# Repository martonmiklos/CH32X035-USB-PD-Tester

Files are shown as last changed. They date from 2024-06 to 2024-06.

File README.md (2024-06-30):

### What?

[This is the clone of this project](https://github.com/wagiminator/CH32X035-USB-PD-Tester)

Differences:
- Kicad 7+ (instead EasyEda)
- More generic pushbuttons
- Added programmer header
- Added load switch (for testing purposes)
- Changed voltage regulator to 3V3 as the
- Adoptable for LCDs with different pinouts (some exists with swapped GND and VDD pins)

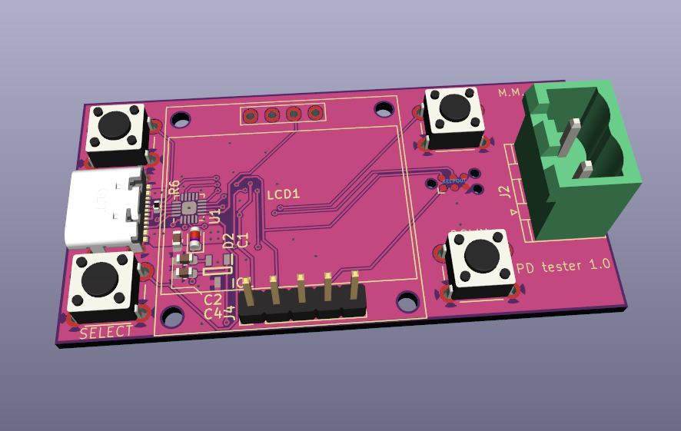
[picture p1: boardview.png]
board view Board


DO NOT BUILD IT YET. Mahor fuckups discovered during board bringup:
- The voltage regulator is not capable of supplying enought current to the LVD

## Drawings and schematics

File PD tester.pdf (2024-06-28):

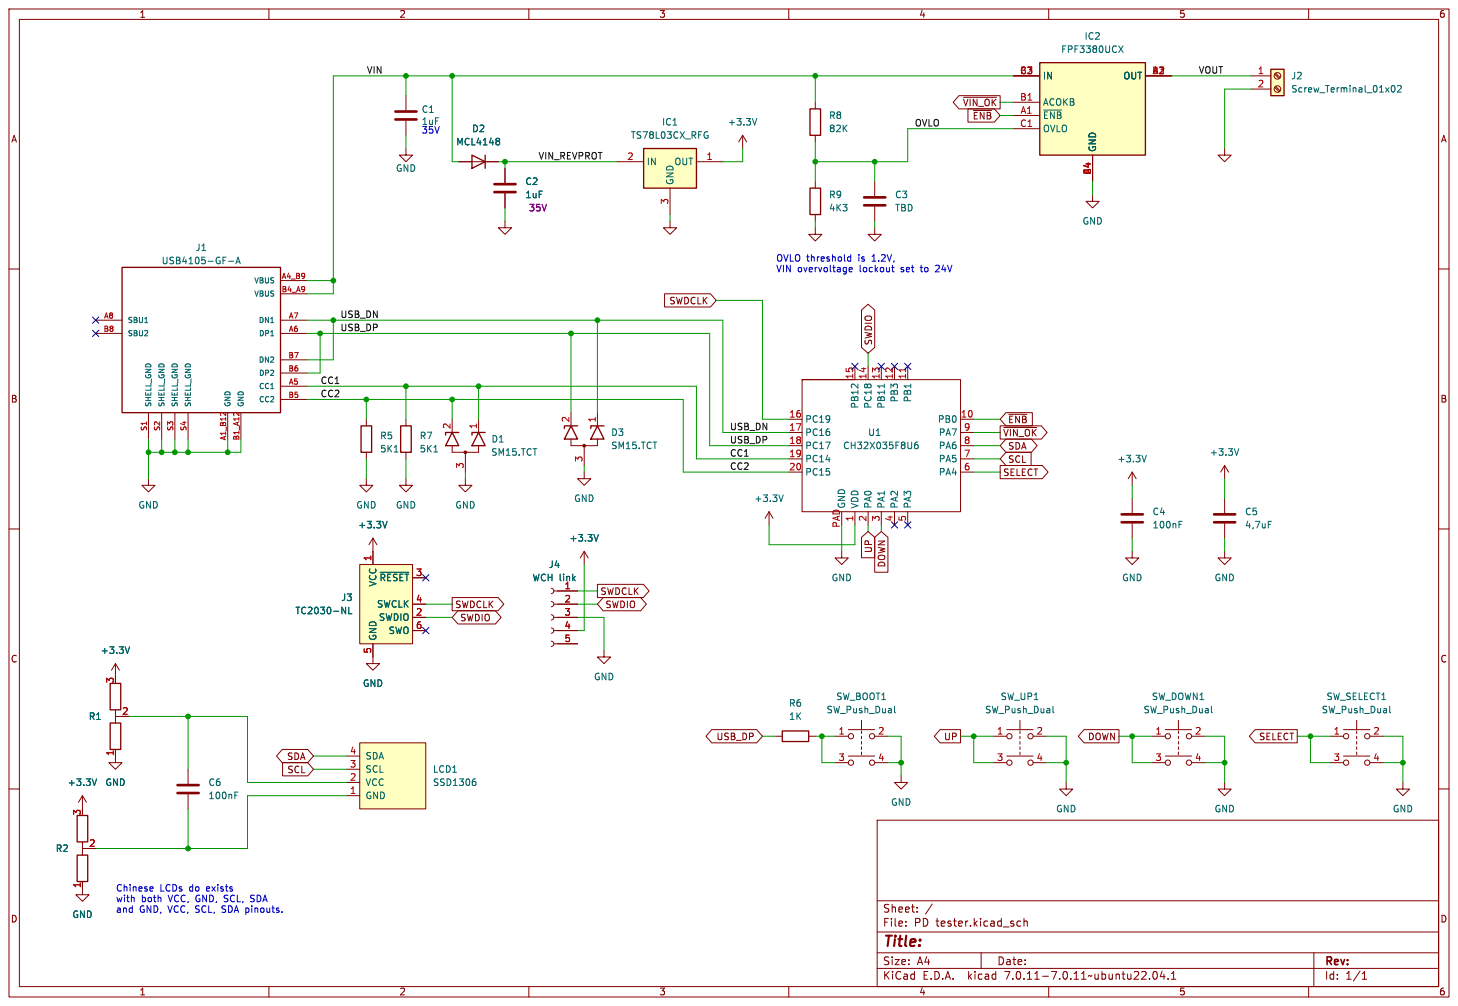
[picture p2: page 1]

J2Screw_Terminal_01x02 GND 1 VCC 2 SCL 3 SDA 4

1 SWDIO 2 ~{RESET}3 SWCLK 4 GND

Id: 1/1 Title: File: PD tester.kicad_sch Sheet: / +3.3V GND GND

Chinese LCDs do exists with both VCC, GND, SCL, SDA

and GND, VCC, SCL, SDA pinouts.

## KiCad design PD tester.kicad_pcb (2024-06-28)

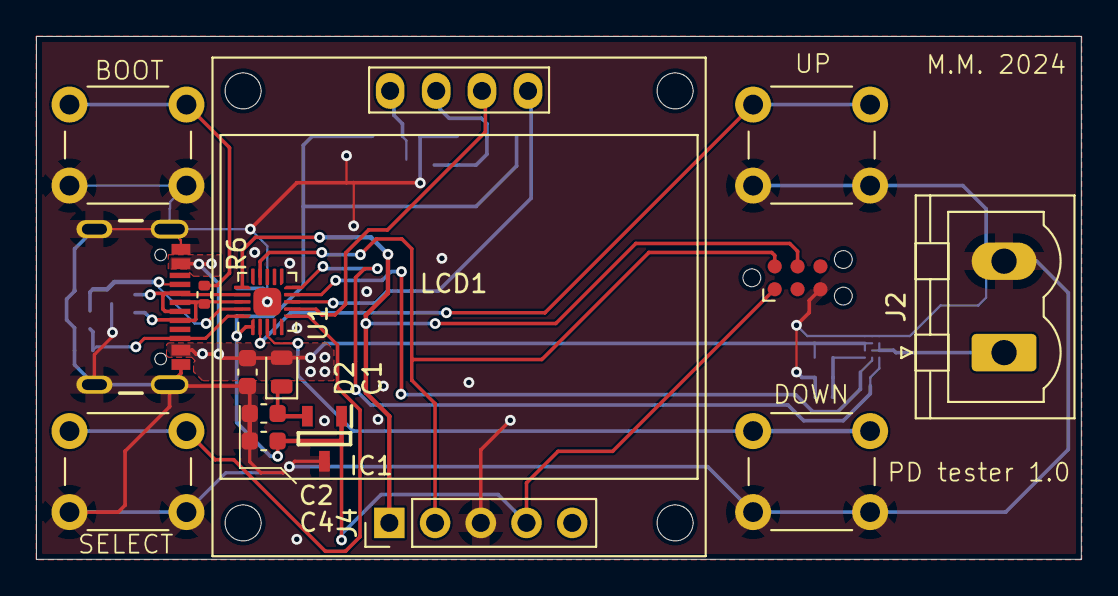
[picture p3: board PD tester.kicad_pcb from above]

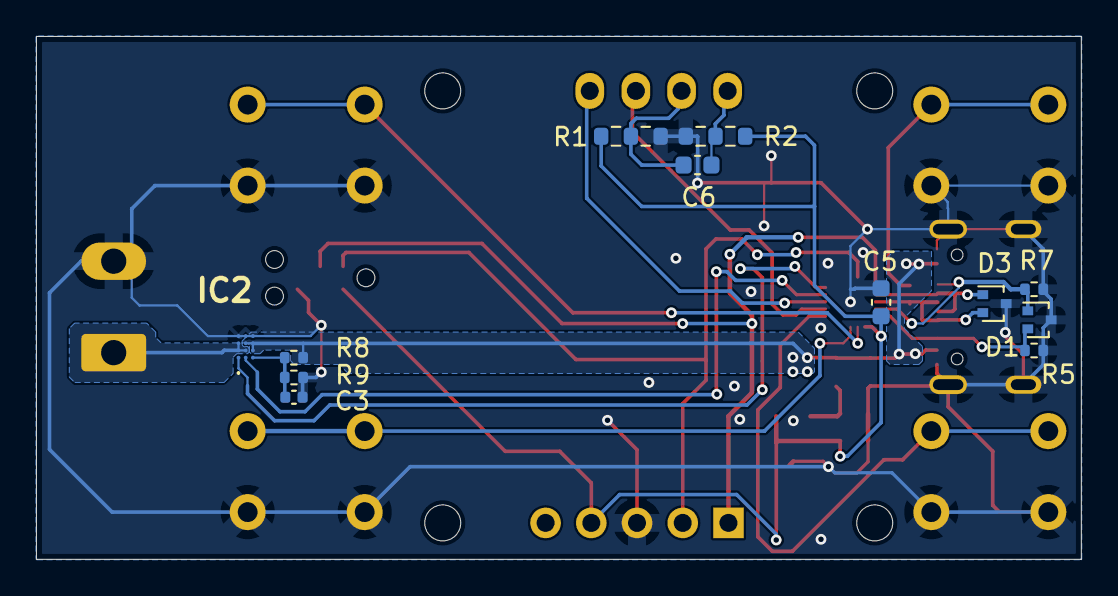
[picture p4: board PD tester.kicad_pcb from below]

Board: 2 copper layers, 58.0 x 29.1 mm, 28 parts (12 on the bottom side), 22 nets.

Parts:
C1, C2: 1uF; C_0603_1608Metric
C3: TBD; C_0402_1005Metric
C4, C6: 100nF; C_0603_1608Metric
C5: 4,7uF; C_0603_1608Metric
D1, D3: SM15.TCT; SOT-416
D2: MCL4148; D_MicroMELF
IC1: TS78L03CX_RFG; SOT95P275X135-3N
IC2: FPF3380UCX
J1: USB4105-GF-A; GCT_USB4105-GF-A_1
J2: Screw_Terminal_01x02; PhoenixContact_MSTBVA_2,5_2-G-5,08_1x02_P5.08mm_Vertical
J3: TC2030-NL; Tag-Connect_TC2030-IDC-NL_2x03_P1.27mm_Vertical
J4: WCH link; PinHeader_1x05_P2.54mm_Vertical
LCD1: SSD1306; 128x64OLED_mounting_holes
R1, R2: R_0603_1608Metric_popopt
R5, R7: 5K1; R_0402_1005Metric
R6: 1K; R_0402_1005Metric
R8: 82K; R_0402_1005Metric
R9: 4K3; R_0402_1005Metric
SW_BOOT1: SW_Push_Dual; SW_PUSH_6mm
SW_DOWN1: SW_Push_Dual; SW_PUSH_6mm
SW_SELECT1: SW_Push_Dual; SW_PUSH_6mm
SW_UP1: SW_Push_Dual; SW_PUSH_6mm
U1: CH32X035F8U6; UQFN-20_3x3mm_P0.4mm_w_ep

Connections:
+3.3V: C4.1, C5.1, IC1.1 (OUT), J3.1 (VCC), J4.4, R1.3, R2.3, U1.1 (VDD)
/CC1: D1.1 (K1), J1.A5 (CC1), R7.1, U1.19 (PC14)
/CC2: D1.2 (K2), J1.B5 (CC2), R5.1, U1.20 (PC15)
/OVLO: C3.1, IC2.C1 (OVLO), R8.2, R9.1
/USB_DN: D3.1 (K1), J1.A7 (DN1), J1.B7 (DN2), U1.17 (PC16)
/VIN: C1.1, D2.2 (A), IC2.B3 (IN), IC2.C2 (IN), IC2.C3 (IN), J1.A4_B9 (VBUS), J1.B4_A9 (VBUS), R8.1
/VOUT: IC2.A2 (OUT), IC2.A3 (OUT), IC2.B2 (OUT), J2.1
DOWN: SW_DOWN1.1, U1.3 (PA1)
GND: C1.2, C2.2, C3.2, C4.2, C5.2, D1.3 (A), D3.3 (A), IC1.3 (GND), IC2.A4 (GND), IC2.B4 (GND), IC2.C4 (GND), J1.A1_B12 (GND), J1.B1_A12 (GND), J1.S1 (SHELL_GND), J1.S2 (SHELL_GND), J1.S3 (SHELL_GND), J1.S4 (SHELL_GND), J2.2, J3.5 (GND), J4.3, R1.1, R2.1, R5.2, R7.2, R9.2, SW_BOOT1.2, SW_DOWN1.2, SW_SELECT1.2, SW_UP1.2, U1.PAD (GND)
unnamed: C2.1, D2.1 (K), IC1.2 (IN)
unnamed: C6.2, LCD1.1 (GND), R2.2
unnamed: C6.1, LCD1.2 (VCC), R1.2
unnamed: R6.2, SW_BOOT1.1
SCL: LCD1.3 (SCL), U1.7 (PA5)
SDA: LCD1.4 (SDA), U1.8 (PA6)
SELECT: SW_SELECT1.1, U1.6 (PA4)
SWDCLK: J3.4 (SWCLK), J4.1, U1.16 (PC19)
SWDIO: J3.2 (SWDIO), J4.2, U1.14 (PC18)
UP: SW_UP1.1, U1.2 (PA0)
USB_DP: D3.2 (K2), J1.A6 (DP1), J1.B6 (DP2), R6.1, U1.18 (PC17)
~ENB: IC2.A1 (~ENB), U1.10 (PB0)
~VIN_OK: IC2.B1 (ACOKB), U1.9 (PA7)
